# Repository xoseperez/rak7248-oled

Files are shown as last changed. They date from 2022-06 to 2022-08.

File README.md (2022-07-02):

# Enhancing the RAK7248 WisGate Developer D4H 

Here you can find the 3D model and the code to hack your RAK7248 WisGate Developer Gateway to add an OLED screen with info about the device and the LoraWAN activity.

To know more about the process, steps and expected result, check the blog post at RAKwireless News Blog: https://news.rakwireless.com/enhancing-the-rak7248-wisgate-developer-d4h/

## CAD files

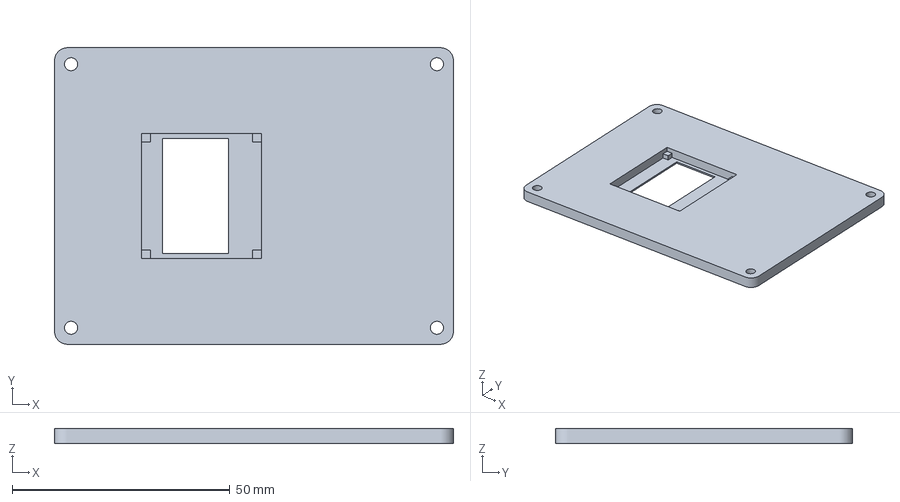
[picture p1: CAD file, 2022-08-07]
3dmodel/rak7248-oled-top.amf
91.6 x 68.1 x 3.40 mm

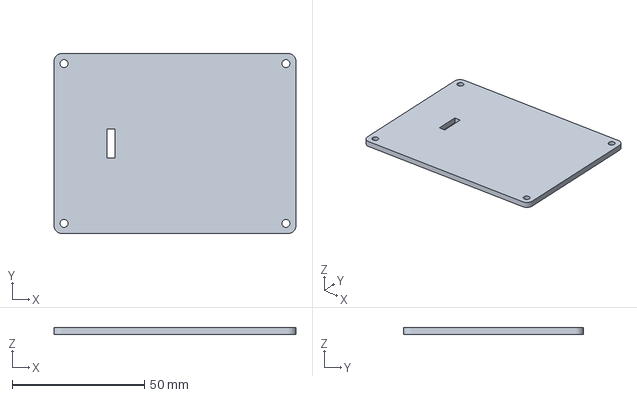
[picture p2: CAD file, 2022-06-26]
3dmodel/rak7248-oled-bottom.amf
91.6 x 68.1 x 2.50 mm

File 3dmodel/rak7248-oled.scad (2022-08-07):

$fn = 50;

LENGTH=91.6;
WIDTH=68.1;
THICKNESS=5.9;
ROUNDED=3.0;
HOLE_DISTANCE=3.8;
HOLE_RADIUS=1.5;

PCB_LENGTH=28.2+0.6;
PCB_WIDTH=27.1+0.4;
PCB_THICKNESS=3.4;
SCREEN_LENGTH=25.5+0.8;
SCREEN_WIDTH=14.3+0.8;
SCREEN_THICKNESS=1.5;
SCREEN_X=(PCB_LENGTH-SCREEN_LENGTH)/2;
SCREEN_Y=4.8;
HEADER_LENGTH=11;
HEADER_WIDTH=3;
HEADER_X=(PCB_LENGTH-HEADER_LENGTH)/2;

module screen() {
    difference() {
        union() {
            linear_extrude(PCB_THICKNESS-0.5)
                square([PCB_LENGTH,PCB_WIDTH], false);
            linear_extrude(PCB_THICKNESS)
                translate([SCREEN_X,SCREEN_Y])
                    square([SCREEN_LENGTH,SCREEN_WIDTH], false);
            translate([HEADER_X,0,-PCB_THICKNESS-1])
                linear_extrude(PCB_THICKNESS+1)
                    square([HEADER_LENGTH,HEADER_WIDTH], false);
        }
        translate([0,0,PCB_THICKNESS-SCREEN_THICKNESS-0.5])
        linear_extrude(SCREEN_THICKNESS) {
            square([2,2]);
            translate([PCB_LENGTH-2,0]) square([2,2]);
            translate([PCB_LENGTH-2,PCB_WIDTH-2]) square([2,2]);
            translate([0,PCB_WIDTH-2]) square([2,2]);
        }
    }
}

module base(thickness) {
    linear_extrude(thickness)
    difference() {
        translate([ROUNDED,ROUNDED])
        minkowski() {
            square([LENGTH-ROUNDED*2, WIDTH-ROUNDED*2], false);
            circle(ROUNDED);
        }
        translate([HOLE_DISTANCE,HOLE_DISTANCE]) circle(HOLE_RADIUS);
        translate([LENGTH-HOLE_DISTANCE,HOLE_DISTANCE]) circle(HOLE_RADIUS);
        translate([HOLE_DISTANCE,WIDTH-HOLE_DISTANCE]) circle(HOLE_RADIUS);
        translate([LENGTH-HOLE_DISTANCE,WIDTH-HOLE_DISTANCE]) circle(HOLE_RADIUS);
    }
}

module top() {
    difference() {
        base(PCB_THICKNESS);
        translate([20,(WIDTH-PCB_LENGTH)/2]) translate([0,PCB_LENGTH]) rotate([0,0,-90]) screen();
    }
}

module bottom() {
    difference() {
        base(THICKNESS - PCB_THICKNESS);
        translate([20,(WIDTH-PCB_LENGTH)/2,PCB_THICKNESS]) 
        translate([0,PCB_LENGTH]) rotate([0,0,-90]) screen();
    }
}

rotate([180,0,0]) top();
//bottom();

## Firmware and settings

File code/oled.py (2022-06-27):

#!/usr/bin/env python3
# -*- coding: utf-8 -*-

__author__ = "Kai Xi 郗锴, Sheng Lyu 吕晟, Taylor Lee 李远朝 & Xose Pérez"
__copyright__ = "Copyright 2022 RAKWireless"
__license__ = "MIT"
__maintainer__ = "RAKWireless"
__email__ = "xose.perez@rakwireless.com"

import sys
import threading
import netifaces
import psutil
import re
import subprocess
import requests
import json
import time

import board
import adafruit_ssd1306
from PIL import Image, ImageDraw, ImageFont

# -----------------------------------------------------------------------------
# Configuration
# -----------------------------------------------------------------------------

WIDTH = 128
HEIGHT = 64
BORDER = 5
DELAY = 5
AVAIL_WIDTH = 120
AVAIL_HIGH = 40
MAX_BUCKET_COUNT = 36
START_WIDTH = 5

# -----------------------------------------------------------------------------
# Pages
# -----------------------------------------------------------------------------

def network(draw):
    
    # Create blank image for drawing
    font = ImageFont.load_default()
    (font_width, font_height) = font.getsize("H")
    y = 0
    
    draw.rectangle((0, 0, oled.width - 1, font_height - 1), outline=255, fill=255)
    draw.text((0, y), "NETWORK", font=font, fill=0)
    y += font_height

    # Get IP
    ifaces = netifaces.interfaces()
    pattern = "^bond.*|^[ewr].*|^br.*|^lt.*|^umts.*|^lan.*"

    # Get bridge interfaces created by docker 
    p = subprocess.run('docker network ls -f driver=bridge --format "br-{{.ID}}"', shell=True, stdout=subprocess.PIPE, stderr=subprocess.PIPE)
    br_docker_ifaces = p.stdout.decode()
    
    for iface in ifaces:
        # Match only interface names starting with e (Ethernet), br (bridge), w (wireless), r (some Ralink drivers use>
        # Get rid off of the br interface created by docker
        if re.match(pattern, iface) and iface not in br_docker_ifaces:
            ifaddresses = netifaces.ifaddresses(iface)
            ipv4_addresses = ifaddresses.get(netifaces.AF_INET)
            if ipv4_addresses:
                for address in ipv4_addresses:
                    addr = address['addr']
                    draw.text((0, y), ("%s: %s" % (iface[:6], addr)), font=font, fill=255)
                    y += font_height

    return True

def stats(draw):
    
    # Create blank image for drawing
    font = ImageFont.load_default()
    (font_width, font_height) = font.getsize("H")
    y = 0
    
    draw.rectangle((0, 0, oled.width - 1, font_height - 1), outline=255, fill=255)
    draw.text((0, y), "STATS", font=font, fill=0)
    y += font_height

    # Get cpu percent
    cpu = psutil.cpu_percent(None)
    draw.text((0, y), ("CPU: %.1f%%" % cpu), font=font, fill=255)
    y += font_height
 
    # Get free memory percent
    memory = 100 - psutil.virtual_memory().percent
    draw.text((0, y), ("Free memory: %.1f%%" % memory), font=font, fill=255)
    y += font_height

    # Get temperature
    p = subprocess.run('vcgencmd measure_temp 2> /dev/null | sed \'s/temp=//\'', shell=True, stdout=subprocess.PIPE, stderr=subprocess.PIPE)
    draw.text((0, y), ("Temperature: %s" % p.stdout.decode()), font=font, fill=255)
    y += font_height

    # Get uptime
    p = subprocess.run('uptime -p | sed \'s/up //\' | sed \'s/ hours*/h/\' | sed \'s/ minutes*/m/\' | sed \'s/,//\'', shell=True, stdout=subprocess.PIPE, stderr=subprocess.PIPE)
    draw.text((0, y), ("Uptime: %s" % p.stdout.decode()), font=font, fill=255)
    y += font_height

    return True

def lorawan(draw):

    font = ImageFont.load_default()
    (font_width, font_height) = font.getsize("H")

    # require bucket data from log2api
    url = "http://127.0.0.1:8888/api/metrics"
    try:
        res = requests.get(url)
    except:
        return False

    bucket_data = json.loads(res.text)
    bucket_count = min(bucket_data.get('bucket_count'), MAX_BUCKET_COUNT)
    bucket_size = bucket_data.get('bucket_size')
    buckets = bucket_data['buckets']
    totals = bucket_data['totals']
    rx_max = int(totals['rx_max'])
    if rx_max == 0:
        return False

    # calculate the width of each bucket and real bucket count displayed.
    bucket_width = int(AVAIL_WIDTH / bucket_count) - 1

    # calculate the pixel of every packet
    unit = float(AVAIL_HIGH / rx_max)

    # draw y-axis, the packet count of each bucket.
    draw.line((3, 0, 3, 60), width=1, fill=128)
    draw.line((3, 0, 0, 3), width=1, fill=128)
    draw.line((3, 0, 6, 3), width=1, fill=128)

    # draw x-axis, the time.
    draw.line((3, 60, 127, 60), width=1, fill=128)
    draw.line((124, 63, 127, 60), width=1, fill=128)
    draw.line((124, 57, 127, 60), width=1, fill=128)
    draw.text((121, 45), "t", font=font, fill=255)

    # draw every bucket 
    for i in range(bucket_count):
        tmp = buckets.get(str(i), {'rx': 0, 'tx': 0})
        rx = tmp['rx']
        draw.rectangle(
            (START_WIDTH + i * bucket_width, 60, START_WIDTH + (i + 1) * bucket_width - 2, 60 - int(rx * unit) - 1), 
            outline=1, 
            fill=1
        )
    
    # draw top line
    top = "LAST %dm, MAX:%d"%(bucket_count * bucket_size / 60, rx_max)
    draw.text((10, 0), top, font=font, fill=255)
    
    return True

# -----------------------------------------------------------------------------
# State machine
# -----------------------------------------------------------------------------

def show_page(page):

    # Prepare canvas
    image = Image.new("1", (oled.width, oled.height))
    draw = ImageDraw.Draw(image)

    response = False
    while not response:
        
        # Show page (returns false if the page should not be displayed)
        response = pages[page](draw)
        
        # Update next page
        # We are not showing page 0 (intro) again
        page = page + 1
        if page >= len(pages):
            page = 0


    # Update screen
    oled.fill(0)
    oled.image(image)
    oled.show()
    
    # Return pointer to next page
    return page

# -----------------------------------------------------------------------------
# Main loop
# -----------------------------------------------------------------------------

class RepeatTimer(threading.Timer):
    page = 0
    def run(self):
        while not self.finished.wait(self.interval):
            self.page = self.function(self.page, *self.args, **self.kwargs)

try:
    i2c = board.I2C()
    time.sleep(1)
    oled = adafruit_ssd1306.SSD1306_I2C(WIDTH, HEIGHT, i2c)
except Exception:
    print("OLED screen not found")
    sys.exit()

pages = [network, stats, lorawan]
show_page(0)
timer = RepeatTimer(DELAY, show_page)
timer.start()

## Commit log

2022-07-02 Refactor folders, add gcode files
    [rak7248-oled-bottom.amf, rak7248-oled-top.amf, rak7248-oled.scad]
2022-08-07 Smaller window for the OLED screen
    [rak7248-oled-top.amf, rak7248-oled.scad]
